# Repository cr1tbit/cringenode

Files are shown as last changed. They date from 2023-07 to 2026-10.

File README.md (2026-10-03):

# MOSNode

### A hackable IoT load switch prototyping platform

This device was probably the peak of my overengineeringness - I decided to create the most universal board for controlling low voltage outputs (Like LED stripes, motors, etc.).

In the end, it was too annoying to setup the matrix connections, so I just abandoned it.

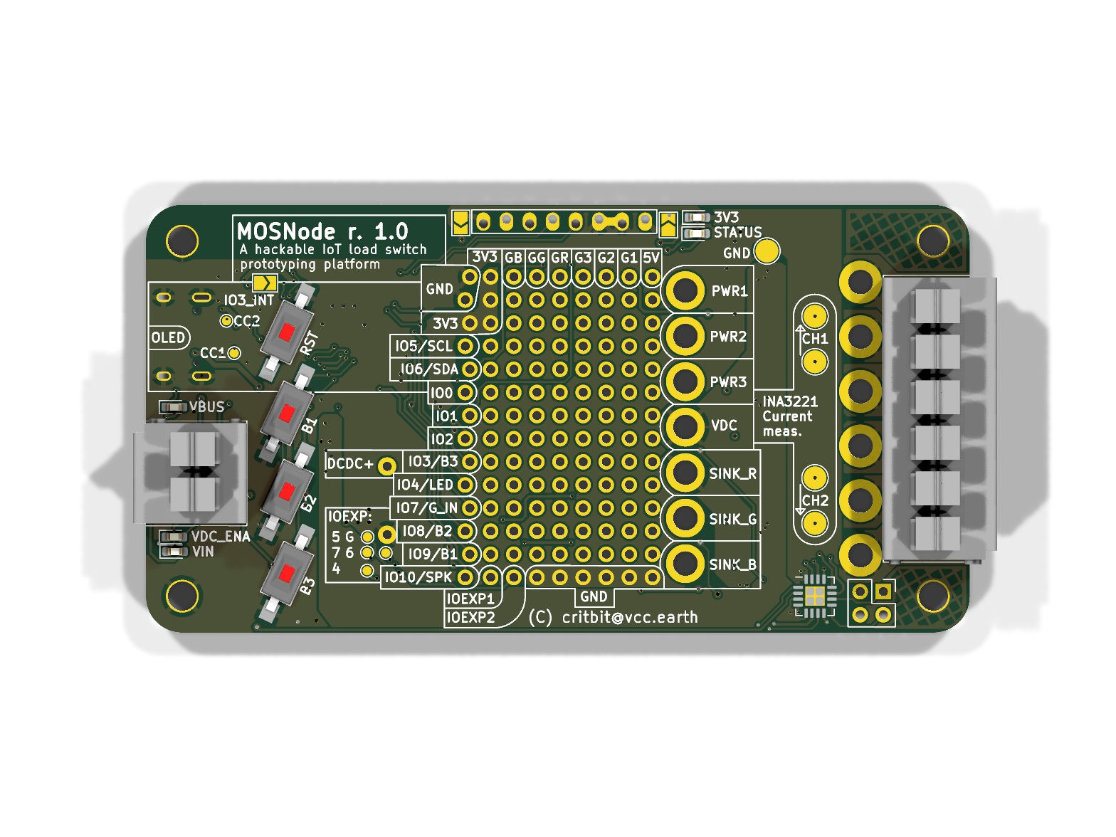
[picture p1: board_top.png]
render of board top


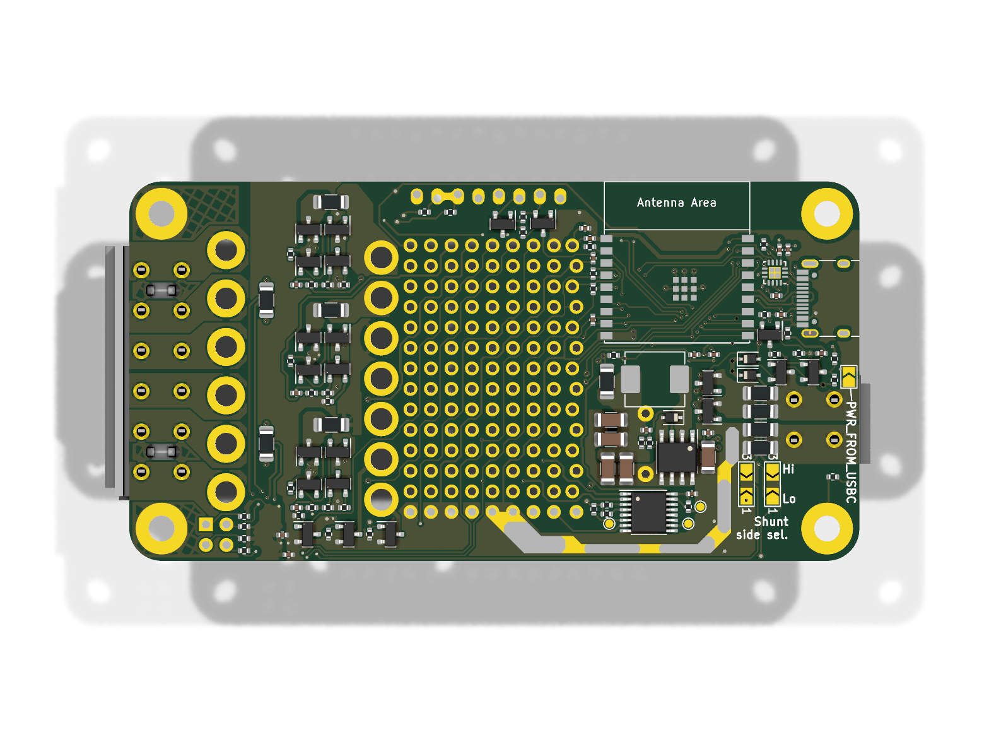
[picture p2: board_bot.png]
render of board bottom


## License

Copyright 2023 Jakub "cr1tbit" Sadowski.

* **Hardware** (KiCad sources, production files and this documentation) is
  licensed under the [CERN-OHL-P v2](LICENSE) (permissive). You may
  redistribute and modify it and make products using it under the terms of
  that licence.
* **Firmware** in [MOSNode-fw/](outduino-fw/) is licensed under the
  [MIT License](outduino-fw/LICENSE).

This source is distributed WITHOUT ANY EXPRESS OR IMPLIED WARRANTY, INCLUDING
OF MERCHANTABILITY, SATISFACTORY QUALITY AND FITNESS FOR A PARTICULAR PURPOSE.
Please see the CERN-OHL-P v2 for applicable conditions.

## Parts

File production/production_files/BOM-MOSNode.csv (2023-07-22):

Comment | Designator | Footprint | LCSC
WST03P06 | Q13,Q17,Q2,Q21,Q3 | SOT-23 | C105166
1k | R10,R29,R30,R32,R38,R43,R48,R53 | R_0402_1005Metric | C11702
FUSB302B01MPX | U5 | WQFN-14-1EP_2.5x2.5mm_P0.5mm_EP1.45x1.45mm | C132291
PCA9557PW | U4 | TSSOP-16_4.4x5mm_P0.65mm | C141380
47uH/2A | L1 | L_Abracon_ASPI-0630LR | C149588
200p | C1,C20,C22,C23,C24,C25,C9 | C_0402_1005Metric | C1530
10u | C11,C12 | C_0402_1005Metric | C15525
USB_C_Receptacle_USB2.0 | J4 | USB_C_Receptacle_HRO_TYPE-C-31-M-12 | C165948
0R/1206 | R12,R13,R3,R41,R46,R51 | R_1206_3216Metric_Pad1.30x1.75mm_HandSolder | C17888
1N5819WS | D1,D2,D3 | D_SOD-323 | C191023
AO3400A | Q4,Q7,Q8 | SOT-23 | C20917
S9015 | Q14,Q18,Q22,Q5 | SOT-23 | C2149
LED_0603 | D4,D5,D6,D7,D8 | LED_0603_1608Metric_Pad1.05x0.95mm_HandSolder | C2290
10k | R11,R14,R15,R20,R21,R22,R23,R24,R25,R26,R33,R34,R35,R36,R37,R40,R42,R45,R47,R5,R50,R52,R6,R7,R8,R9 | R_0402_1005Metric | C25744
15k | R39,R4,R44,R49 | R_0402_1005Metric | C25756
3k | R18,R19,R31 | R_0402_1005Metric | C25890
100n | C10,C13,C14,C15,C16,C17,C18,C19,C21,C8 | C_0402_1005Metric | C307331
50mR/1206 | R1,R2,R27,R28 | R_1206_3216Metric_Pad1.30x1.75mm_HandSolder | C601102
XL1509 | U1 | SOIC-8_3.9x4.9mm_P1.27mm | C74192
MMBT2222A | Q1,Q10,Q12,Q15,Q16,Q19,Q20,Q23,Q6,Q9 | SOT-23 | C8512
47uF/6.3V | C2,C4,C5,C6,C7 | C_1206_3216Metric | C96123
IN+ | J1 | DG235-5.0
FUSB_INT_IO3 | JP6 | SolderJumper-2_P1.3mm_Open_TrianglePad1.0x1.5mm
INA_PAD | TP5 | TestPoint_Pad_D2.5mm
B3 | SW4 | SW_SPST_FSMSM
TERM_BLOCK | J7 | DG235-5.0
CON_PAD | TP4 | MountingHole_2.7mm_M2.5_DIN965_Pad
INA_STA | J8 | PinHeader_2x02_P2.54mm_Vertical
CON_PAD | TP11 | MountingHole_2.7mm_M2.5_DIN965_Pad
INA_PAD | TP9 | TestPoint_Pad_D2.5mm
BOOT/B1 | SW2 | SW_SPST_FSMSM
TERM_BLOCK | J10 | DG235-5.0
TERM_BLOCK | J6 | DG235-5.0
INA_PAD | TP1 | TestPoint_Pad_D2.5mm
IOPAD | TP20 | TestPoint_Pad_D1.0mm
IOPAD | TP14 | TestPoint_Pad_D1.0mm
IOPAD | TP16 | TestPoint_Pad_D1.0mm
GND_PAD | TP2 | TestPoint_Pad_D2.5mm
PWR_FROM_USBC | JP5 | SolderJumper-2_P1.3mm_Open_TrianglePad1.0x1.5mm
TERM_BLOCK | J12 | DG235-5.0
Proto_matrix_14x9+7 | J3 | Proto_matrix_14x9+7
C_THT | C3 | CP_Radial_D10.0mm_P7.50mm
IOPAD | TP15 | TestPoint_Pad_D1.0mm
IN- | J2 | DG235-5.0
IOPAD | TP17 | TestPoint_Pad_D1.0mm
RST | SW1 | SW_SPST_FSMSM
INA3221 | U3 | Texas_RGV_S-PVQFN-N16_EP2.1x2.1mm
B2 | SW3 | SW_SPST_FSMSM
3V3_FROM_USBC | JP4 | SolderJumper-2_P1.3mm_Open_TrianglePad1.0x1.5mm
INA_PAD | TP6 | TestPoint_Pad_D2.5mm
TERM_BLOCK | J11 | DG235-5.0
CON_PAD | TP8 | MountingHole_2.7mm_M2.5_DIN965_Pad
CON_PAD | TP3 | MountingHole_2.7mm_M2.5_DIN965_Pad
Lichtenprog_conn | J5 | Lichtenprog
IOPAD | TP19 | TestPoint_Pad_D1.0mm
CON_PAD | TP10 | MountingHole_2.7mm_M2.5_DIN965_Pad
TERM_BLOCK | J9 | DG235-5.0
CON_PAD | TP7 | MountingHole_2.7mm_M2.5_DIN965_Pad
ESP32-C3-WROOM-02 | U2 | ESP32-C3-WROOM-02
IOPAD | TP12 | TestPoint_Pad_D1.0mm
SCR | H4 | MountingHole_3.2mm_M3_Pad_TopOnly
SolderJumper_3_Open | JP2 | SolderJumper-3_P2.0mm_Open_TrianglePad1.0x1.5mm_NumberLabels
SCR | H1 | MountingHole_3.2mm_M3_Pad_TopOnly
IOPAD | TP13 | TestPoint_Pad_D1.0mm
PWR_FROM_USBC | JP1 | SolderJumper-2_P1.3mm_Open_TrianglePad1.0x1.5mm
IOPAD | TP18 | TestPoint_Pad_D1.0mm
SCR | H3 | MountingHole_3.2mm_M3_Pad_TopOnly
SCR | H2 | MountingHole_3.2mm_M3_Pad_TopOnly
SolderJumper_3_Open | JP3 | SolderJumper-3_P2.0mm_Open_TrianglePad1.0x1.5mm_NumberLabels

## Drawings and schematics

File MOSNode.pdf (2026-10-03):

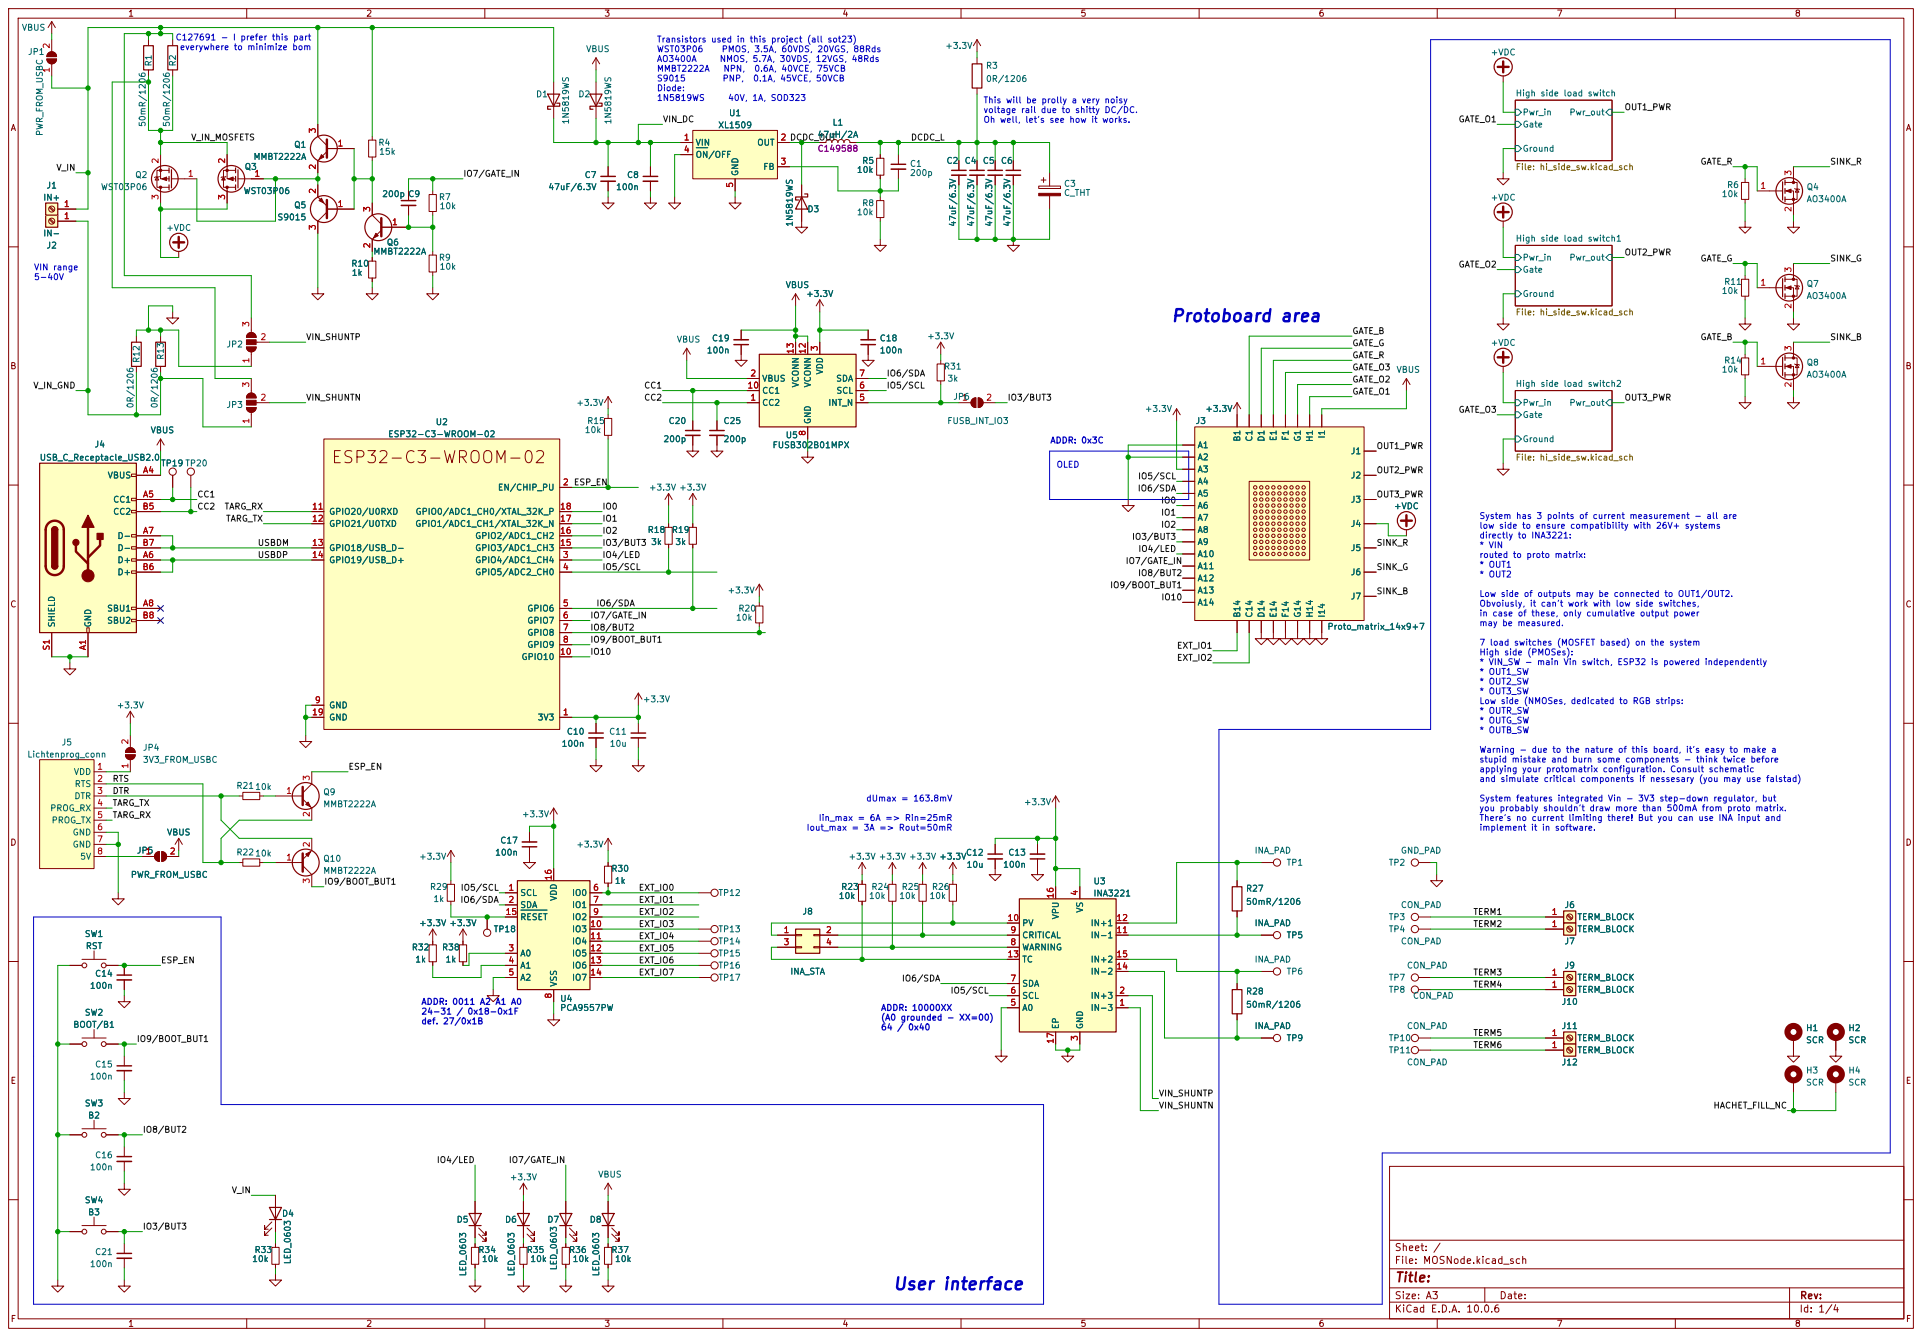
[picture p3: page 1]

voltage rail due to shitty DC/DC. Oh well, let's see how it works. User interface

everywhere to minimize bom

This will be prolly a very noisy

System has 3 points of current measurement - all are
low side to ensure compatibility with 26V+ systems
directly to INA3221: * VIN

routed to proto matrix: * OUT1

* OUT2 Low side of outputs may be connected to OUT1/OUT2.

Obvoiusly, it can't work with low side switches,
in case of these, only cumulative output power may be measured. 7 load switches (MOSFET based) on the system

High side (PMOSes): * VIN_SW - main Vin switch, ESP32 is powered independently

Warning - due to the nature of this board, it's easy to make a
stupid mistake and burn some components - think twice before applying your protomatrix configuration. Consult schematic and simulate critical components if nessesary (you may use falstad)

System features integrated Vin - 3V3 step-down regulator, but you probably shouldn't draw more than 500mA from proto matrix. There's no current limiting there! But you can use INA input and

implement it in software.

IN-2 14 IN+2 15 VPU 16 EP 17

Size: A3 | Rev: | F Date:
KiCad E.D.A. 10.0.6 | Id: 1/4

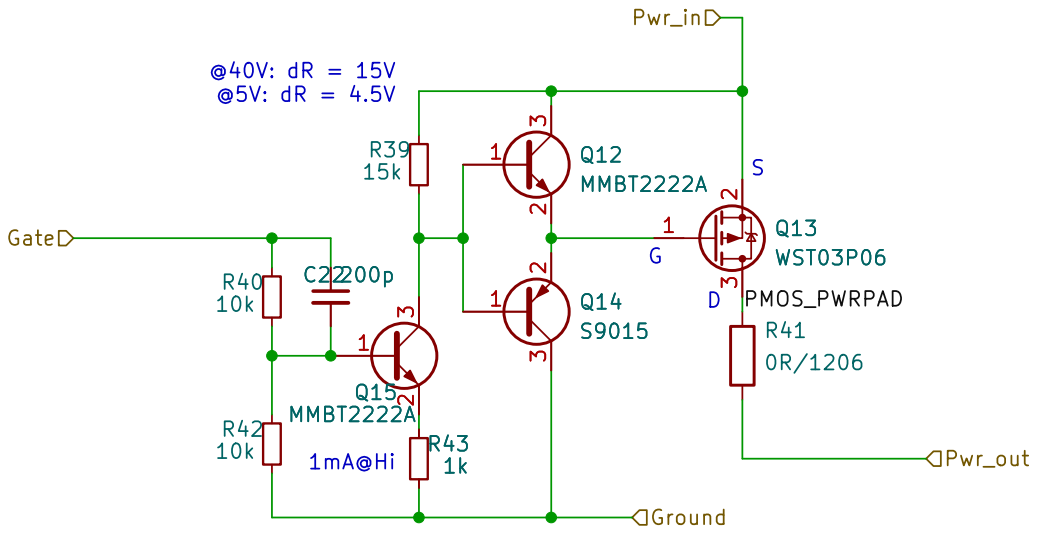
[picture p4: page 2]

Sheet: /High side load switch1/
File: hi_side_sw.kicad_sch
Title:

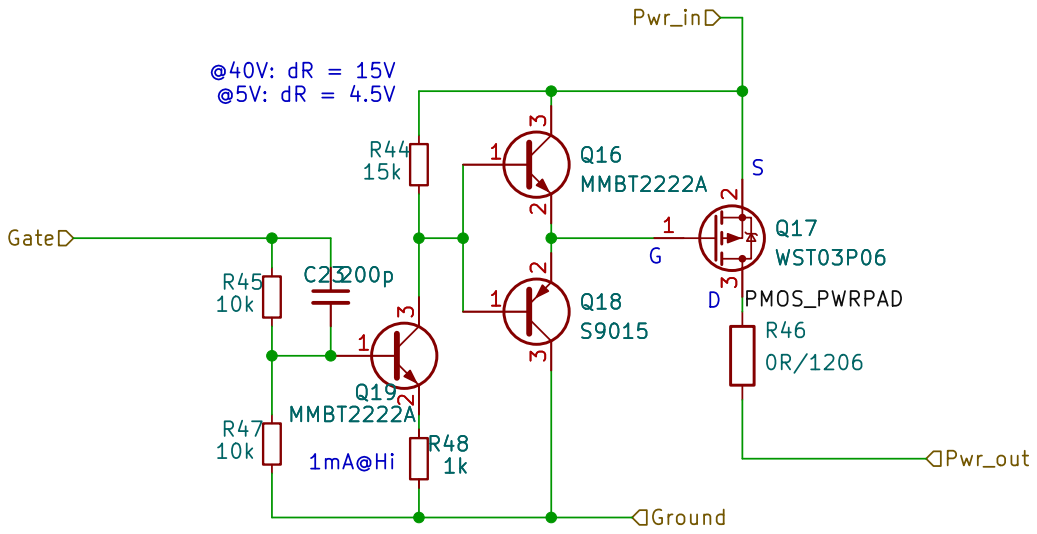
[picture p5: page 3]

Sheet: /High side load switch/
File: hi_side_sw.kicad_sch
Title:

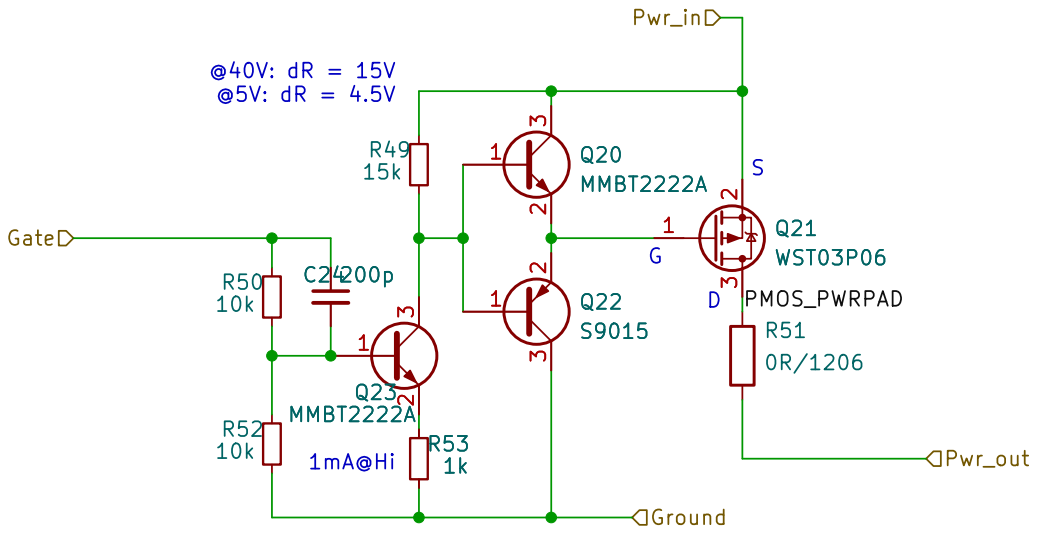
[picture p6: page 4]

Sheet: /High side load switch2/
File: hi_side_sw.kicad_sch
Title:

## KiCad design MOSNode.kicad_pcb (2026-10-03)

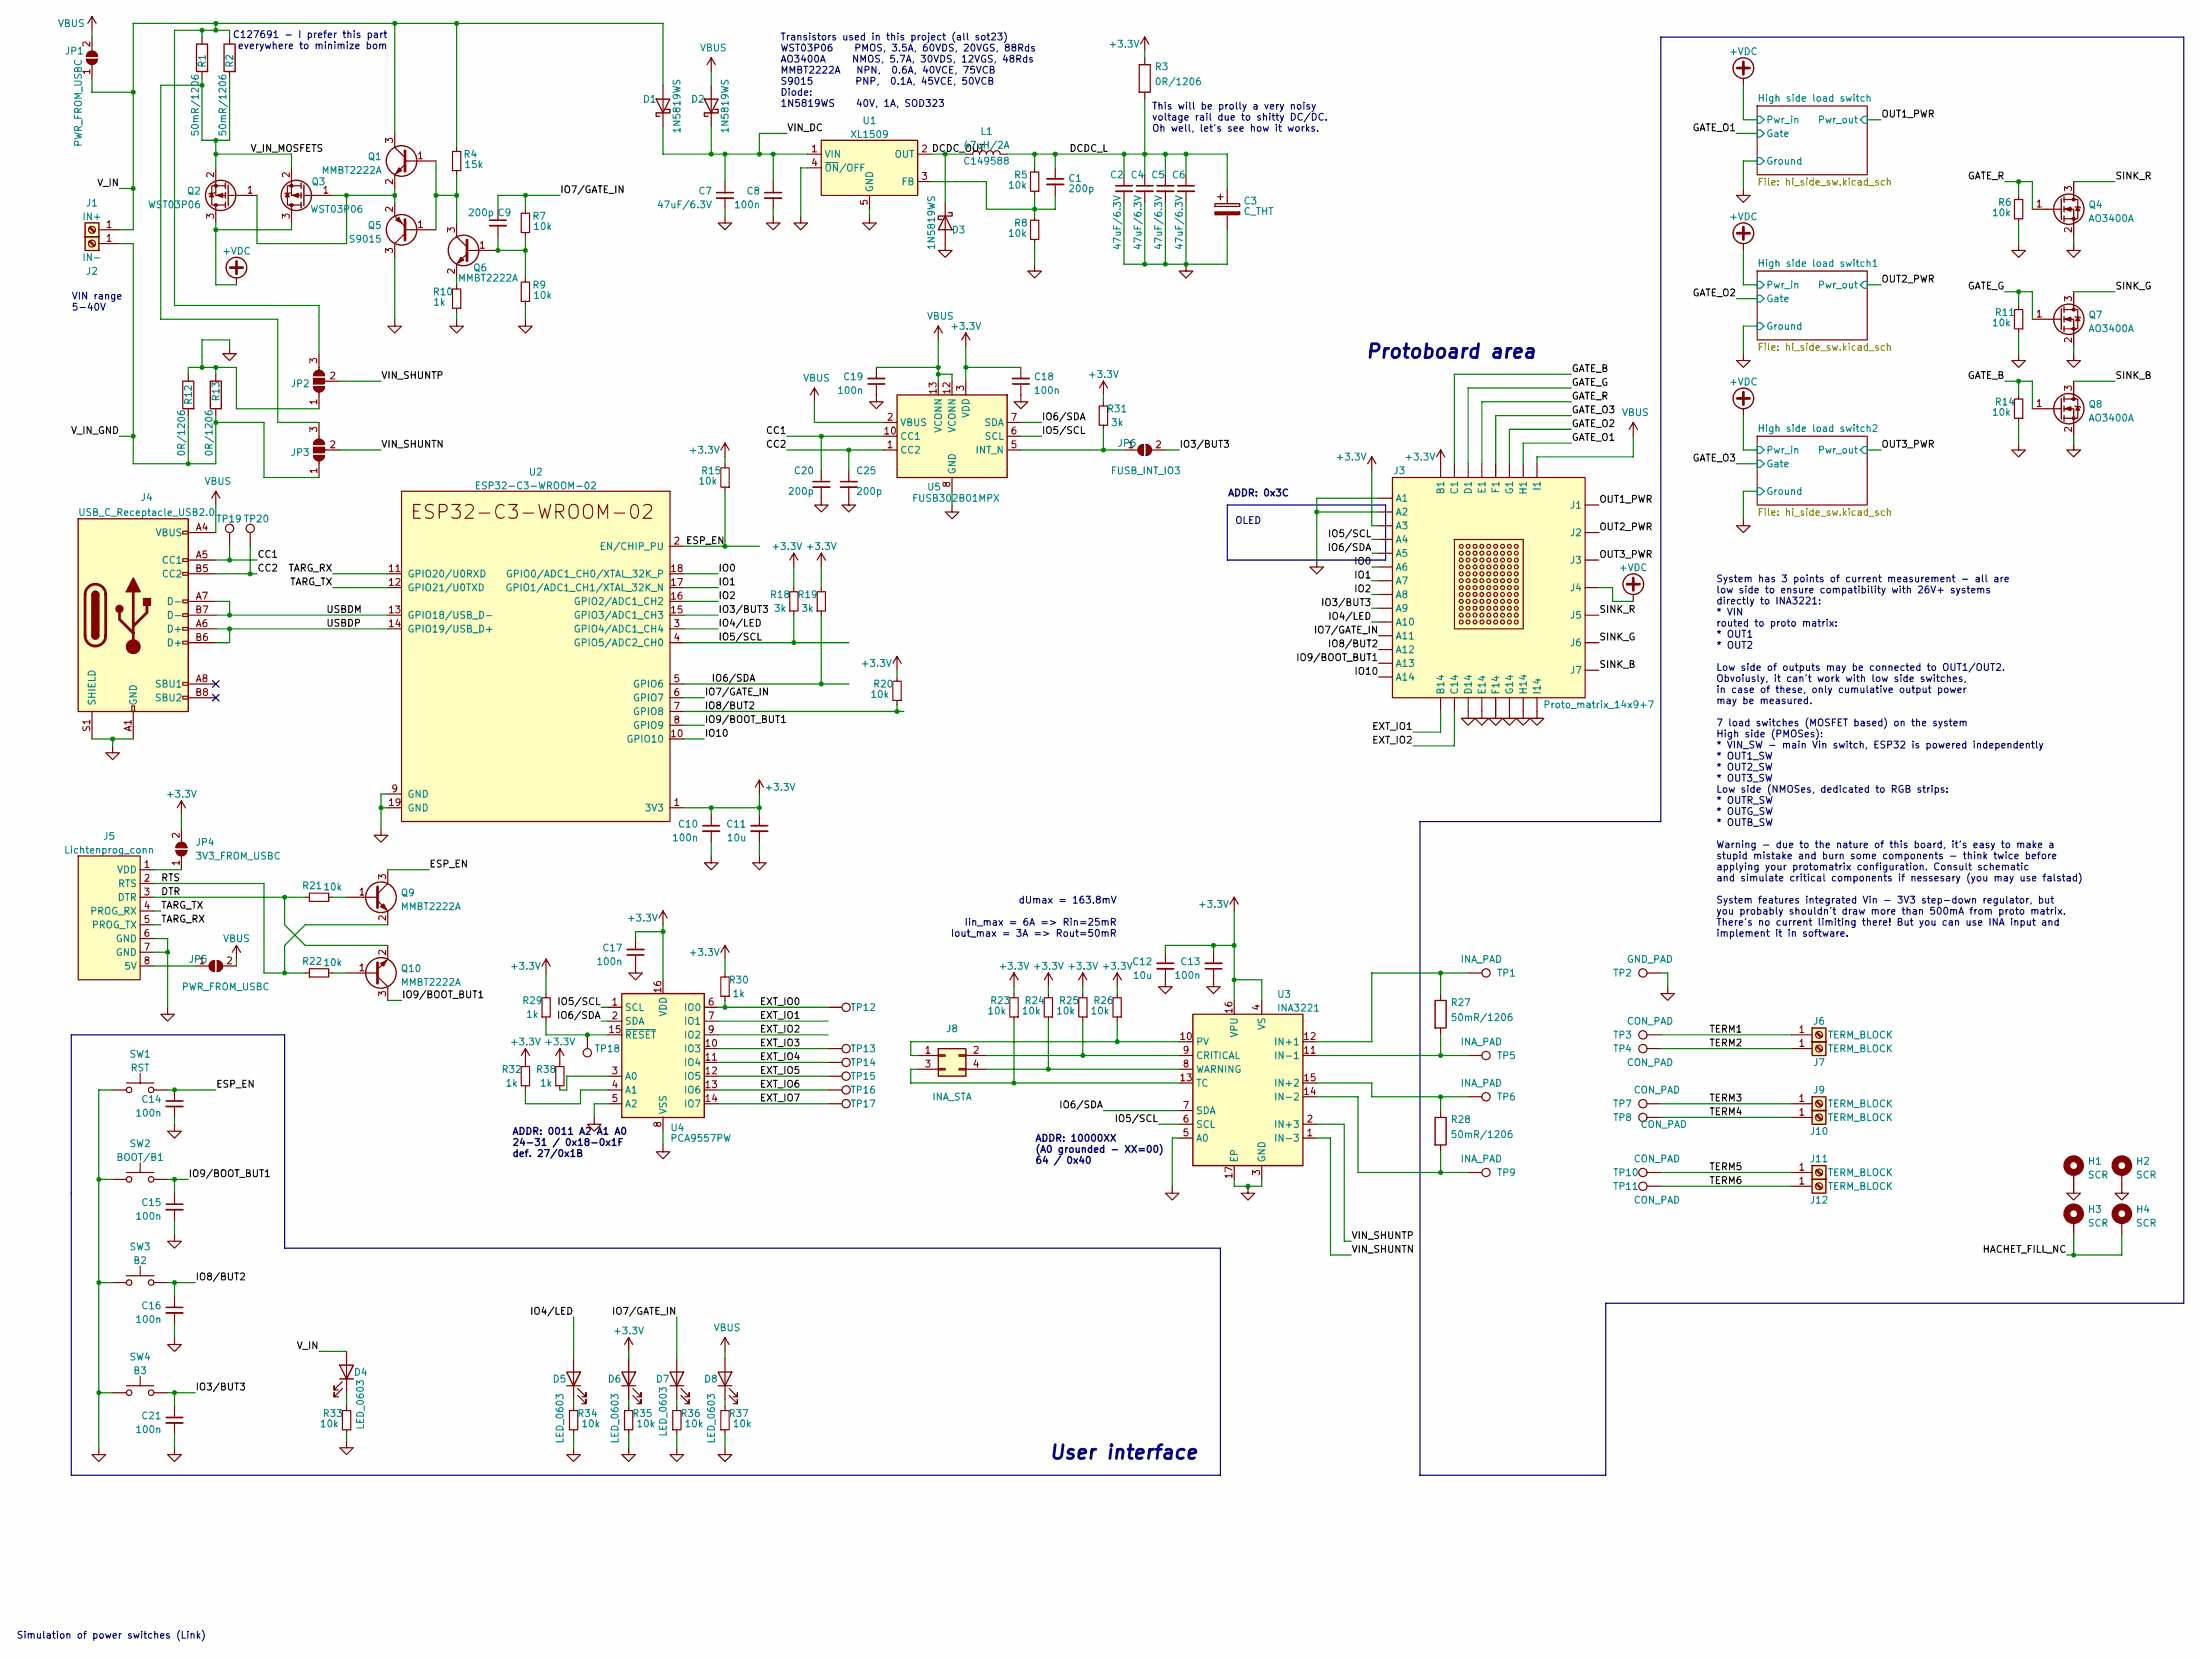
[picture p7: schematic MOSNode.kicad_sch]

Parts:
C1, C9, C20, C25: 200p; C_0402_1005Metric; LCSC C1530
C2, C4, C5, C6, C7: 47uF/6.3V; C_1206_3216Metric; LCSC C96123
C3: C_THT; CP_Radial_D10.0mm_P7.50mm; LCSC DNP
C8, C10, C13, C14, C15, C16, C17, C18, C19, C21: 100n; C_0402_1005Metric; LCSC C307331
C11, C12: 10u; C_0402_1005Metric; LCSC C15525
D1, D2, D3: 1N5819WS; D_SOD-323; LCSC C191023
D4, D5, D6, D7, D8: LED_0603; LED_0603_1608Metric_Pad1.05x0.95mm_HandSolder; LCSC C2290
H1, H2, H3, H4: SCR; MountingHole_3.2mm_M3_Pad_TopOnly; LCSC DNP
J1: IN+; DG235-5.0; LCSC DNP
J2: IN-; DG235-5.0; LCSC DNP
J3: Proto_matrix_14x9+7; LCSC DNP
J4: USB_C_Receptacle_USB2.0; USB_C_Receptacle_HRO_TYPE-C-31-M-12; LCSC C165948
J5: Lichtenprog_conn; Lichtenprog; LCSC DNP
J6, J7, J9, J10, J11, J12: TERM_BLOCK; DG235-5.0; LCSC DNP
J8: INA_STA; PinHeader_2x02_P2.54mm_Vertical; LCSC DNP
JP1, JP5: PWR_FROM_USBC; SolderJumper-2_P1.3mm_Open_TrianglePad1.0x1.5mm; LCSC DNP
JP2, JP3: SolderJumper_3_Open; SolderJumper-3_P2.0mm_Open_TrianglePad1.0x1.5mm_NumberLabels; LCSC DNP
JP4: 3V3_FROM_USBC; SolderJumper-2_P1.3mm_Open_TrianglePad1.0x1.5mm; LCSC DNP
JP6: FUSB_INT_IO3; SolderJumper-2_P1.3mm_Open_TrianglePad1.0x1.5mm; LCSC DNP
L1: 47uH/2A; L_Abracon_ASPI-0630LR; JLC C149588
Q1, Q6, Q9, Q10: MMBT2222A; SOT-23; LCSC C8512
Q2, Q3: WST03P06; SOT-23; LCSC C105166
Q4, Q7, Q8: AO3400A; SOT-23; LCSC C20917
Q5: S9015; SOT-23; LCSC C2149
R1, R2, R27, R28: 50mR/1206; R_1206_3216Metric_Pad1.30x1.75mm_HandSolder; LCSC C601102
R3, R12, R13: 0R/1206; R_1206_3216Metric_Pad1.30x1.75mm_HandSolder; LCSC C17888
R4: 15k; R_0402_1005Metric; LCSC C25756
R5, R6, R7, R8, R9, R11, R14, R15, R20, R21, R22, R23, R24, R25, R26, R33, R34, R35, R36, R37: 10k; R_0402_1005Metric; LCSC C25744
R10, R29, R30, R32, R38: 1k; R_0402_1005Metric; LCSC C11702
R18, R19, R31: 3k; R_0402_1005Metric; LCSC C25890
SW1: RST; SW_SPST_FSMSM; LCSC DNP
SW2: BOOT/B1; SW_SPST_FSMSM; LCSC DNP
SW3: B2; SW_SPST_FSMSM; LCSC DNP
SW4: B3; SW_SPST_FSMSM; LCSC DNP
TP1, TP5, TP6, TP9: INA_PAD; TestPoint_Pad_D2.5mm; LCSC DNP
TP2: GND_PAD; TestPoint_Pad_D2.5mm; LCSC DNP
TP3, TP4, TP7, TP8, TP10, TP11: CON_PAD; MountingHole_2.7mm_M2.5_DIN965_Pad; LCSC DNP
TP12, TP13, TP14, TP15, TP16, TP17, TP18, TP19, TP20: IOPAD; TestPoint_Pad_D1.0mm; LCSC DNP
U1: XL1509; SOIC-8_3.9x4.9mm_P1.27mm; LCSC C74192
U2: ESP32-C3-WROOM-02; LCSC DNP
U3: INA3221; Texas_RGV_S-PVQFN-N16_EP2.1x2.1mm; LCSC DNP
U4: PCA9557PW; TSSOP-16_4.4x5mm_P0.65mm; LCSC C141380
U5: FUSB302B01MPX; WQFN-14-1EP_2.5x2.5mm_P0.5mm_EP1.45x1.45mm; LCSC C132291

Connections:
+3.3V: C10.1, C11.1, C12.1, C13.2, C17.2, C18.2, D6.2 (A), J3.A3, J3.B1, JP4.2 (B), R3.1, R15.2, R18.2, R19.2, R20.2, R23.2, R24.2, R25.2, R26.2, R29.2, R30.2, R31.2, R32.2, R38.2, U2.1 (3V3), U3.4 (VS), U3.16 (VPU), U4.16 (VDD), U5.3 (VDD), U5.4 (VDD)
+VDC: J3.J4, Q2.3 (S), Q3.3 (S); also elsewhere on the board
/CC1: C20.1, J4.A5 (CC1), TP19.1, U5.10 (CC1), U5.11 (CC1)
/CC2: C25.1, J4.B5 (CC2), TP20.1, U5.1 (CC2), U5.14 (CC2)
/DCDC_L: C1.1, C2.1, C3.1, C4.1, C5.1, C6.1, L1.2, R3.2, R5.2
/DCDC_OUT: D3.1 (K), L1.1, U1.2 (OUT)
/DTR: J5.3 (DTR), Q10.2 (E), R21.1
/ESP_EN: C14.1, Q9.3 (C), R15.1, SW1.2, U2.2 (EN/CHIP_PU)
/EXT_IO0: R30.1, TP12.1, U4.6 (IO0)
/EXT_IO1: J3.B14, U4.7 (IO1)
/EXT_IO2: J3.C14, U4.9 (IO2)
/EXT_IO3: TP13.1, U4.10 (IO3)
/EXT_IO4: TP14.1, U4.11 (IO4)
/EXT_IO5: TP15.1, U4.12 (IO5)
/EXT_IO6: TP16.1, U4.13 (IO6)
/EXT_IO7: TP17.1, U4.14 (IO7)
/GATE_B: J3.C1, Q8.1 (G), R14.2
/GATE_G: J3.D1, Q7.1 (G), R11.2
/GATE_O1: J3.H1; also elsewhere on the board
/GATE_O2: J3.G1; also elsewhere on the board
/GATE_O3: J3.F1; also elsewhere on the board
/GATE_R: J3.E1, Q4.1 (G), R6.2
/HACHET_FILL_NC: H3.1, H4.1
/IO0: J3.A6, U2.18 (GPIO0/ADC1_CH0/XTAL_32K_P)
/IO1: J3.A7, U2.17 (GPIO1/ADC1_CH1/XTAL_32K_N)
/IO2: J3.A8, U2.16 (GPIO2/ADC1_CH2)
/IO3/BUT3: C21.1, J3.A9, JP6.2 (B), SW4.2, U2.15 (GPIO3/ADC1_CH3)
/IO4/LED: D5.2 (A), J3.A10, U2.3 (GPIO4/ADC1_CH4)
/IO5/SCL: J3.A4, R18.1, U2.4 (GPIO5/ADC2_CH0), U3.6 (SCL), U4.1 (SCL), U5.6 (SCL)
/IO6/SDA: J3.A5, R19.1, U2.5 (GPIO6), U3.7 (SDA), U4.2 (SDA), U5.7 (SDA)
/IO7/GATE_IN: C9.1, D7.2 (A), J3.A11, R7.2, U2.6 (GPIO7)
/IO8/BUT2: C16.1, J3.A12, R20.1, SW3.2, U2.7 (GPIO8)
/IO9/BOOT_BUT1: C15.1, J3.A13, Q10.3 (C), SW2.2, U2.8 (GPIO9)
/IO10: J3.A14, U2.10 (GPIO10)
/OUT1_PWR: J3.J1; also elsewhere on the board
/OUT2_PWR: J3.J2; also elsewhere on the board
/OUT3_PWR: J3.J3; also elsewhere on the board
/RTS: J5.2 (RTS), Q9.2 (E), R22.1
/SINK_B: J3.J7, Q8.3 (D)
/SINK_G: J3.J6, Q7.3 (D)
/SINK_R: J3.J5, Q4.3 (D)
/TARG_RX: J5.5 (PROG_TX), U2.11 (GPIO20/U0RXD)
/TARG_TX: J5.4 (PROG_RX), U2.12 (GPIO21/U0TXD)
/TERM1: J6.1, TP3.1
/TERM2: J7.1, TP4.1
/TERM3: J9.1, TP7.1
/TERM4: J10.1, TP8.1
/TERM5: J11.1, TP10.1
/TERM6: J12.1, TP11.1
/USBDM: J4.A7 (D-), J4.B7 (D-), U2.13 (GPIO18/USB_D-)
/USBDP: J4.A6 (D+), J4.B6 (D+), U2.14 (GPIO19/USB_D+)
/VIN_DC: C7.1, C8.1, D1.1 (K), D2.1 (K), U1.1 (VIN)
/VIN_SHUNTN: JP3.2 (C), U3.1 (IN-3)
/VIN_SHUNTP: JP2.2 (C), U3.2 (IN+3)
/V_IN: D1.2 (A), D4.2 (A), J1.1, JP1.1 (A), JP2.3 (B), Q1.3 (C), R1.1, R2.1, R4.2
/V_IN_GND: J2.1, JP3.1 (A), R12.2, R13.2
/V_IN_MOSFETS: JP3.3 (B), Q2.2 (D), Q3.2 (D), R1.2, R2.2
GND: C2.2, C3.2, C4.2, C5.2, C6.2, C7.2, C8.2, C10.2, C11.2, C12.2, C13.1, C14.2, C15.2, C16.2, C17.1, C18.1, C19.1, C20.2, C21.2, C25.2, D3.2 (A), H1.1, H2.1, J3.A1, J3.A2, J3.D14, J3.E14, J3.F14, J3.G14, J3.H14, J3.I14, J4.A1 (GND), J4.A12 (GND), J4.B1 (GND), J4.B12 (GND), J4.S1 (SHIELD), J5.6 (GND), J5.7 (GND), JP2.1 (A), Q4.2 (S), Q5.3 (C), Q7.2 (S), Q8.2 (S), R6.1, R8.1, R9.1, R10.1, R11.1, R12.1, R13.1, R14.1, R33.1, R34.1, R35.1, R36.1, R37.1, SW1.1, SW2.1, SW3.1, SW4.1, TP2.1, U1.4 (~ON/OFF), U1.5 (GND), U1.6 (GND), U1.7 (GND), U1.8 (GND), U2.9 (GND), U2.19 (GND), U3.3 (GND), U3.5 (A0), U3.17 (EP), U4.5 (A2), U4.8 (VSS), U5.8 (GND), U5.9 (GND), U5.15 (GND); also elsewhere on the board
unnamed: D4.1 (K), R33.2
unnamed: D5.1 (K), R34.2
unnamed: D6.1 (K), R35.2
unnamed: D7.1 (K), R36.2
unnamed: D8.1 (K), R37.2
unnamed: J5.8 (5V), JP5.1 (A)
unnamed: J5.1 (VDD), JP4.1 (A)
unnamed: J8.1, R26.1, U3.10 (PV)
unnamed: J8.2, R25.1, U3.9 (CRITICAL)
unnamed: J8.3, R23.1, U3.13 (TC)
unnamed: J8.4, R24.1, U3.8 (WARNING)
unnamed: JP6.1 (A), R31.1, U5.5 (INT_N)
unnamed: Q1.1 (B), Q5.1 (B), Q6.3 (C), R4.1
unnamed: Q1.2 (E), Q2.1 (G), Q3.1 (G), Q5.2 (E)
unnamed: C9.2, Q6.1 (B), R7.1, R9.2
unnamed: Q6.2 (E), R10.2
unnamed: Q9.1 (B), R21.2
unnamed: Q10.1 (B), R22.2
unnamed: C1.2, R5.1, R8.2, U1.3 (FB)
unnamed: R27.1, TP1.1, U3.12 (IN+1)
unnamed: R28.1, TP6.1, U3.15 (IN+2)
unnamed: R27.2, TP5.1, U3.11 (IN-1)
unnamed: R28.2, TP9.1, U3.14 (IN-2)
unnamed: R38.1, U4.3 (A0)
unnamed: R32.1, U4.4 (A1)
unnamed: R29.1, TP18.1, U4.15 (~RESET)
VBUS: C19.2, D2.2 (A), D8.2 (A), J3.I1, J4.A4 (VBUS), J4.A9 (VBUS), J4.B4 (VBUS), J4.B9 (VBUS), JP1.2 (B), JP5.2 (B), U5.2 (VBUS), U5.12 (VCONN), U5.13 (VCONN)

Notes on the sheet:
ADDR: 0011 A2 A1 A0 24-31 / 0x18-0x1F def. 27/0x1B
Transistors used in this project (all sot23) WST03P06 PMOS, 3.5A, 60VDS, 20VGS, 88Rds AO3400A NMOS, 5.7A, 30VDS, 12VGS, 48Rds MMBT2222A NPN, 0.6A, 40VCE, 75VCB S9015 PNP, 0.1A, 45VCE, 50VCB Diode: 1N5819WS 40V, 1A, SOD323
Protoboard area
ADDR: 10000XX (A0 grounded - XX=00) 64 / 0x40
System has 3 points of current measurement - all are low side to ensure compatibility with 26V+ systems directly to INA3221: * VIN routed to proto matrix: * OUT1 * OUT2 Low side of outputs may be connected to OUT1/OUT2. Obvoiusly, it can't work with low side switches, in case of these, only cumulat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
VIN range 5-40V
This will be prolly a very noisy voltage rail due to shitty DC/DC. Oh well, let's see how it works.
OLED
ADDR: 0x3C
User interface
C127691 - I prefer this part everywhere to minimize bom
Simulation of power switches (Link)
dUmax = 163.8mV Iin_max = 6A => Rin=25mR Iout_max = 3A => Rout=50mR

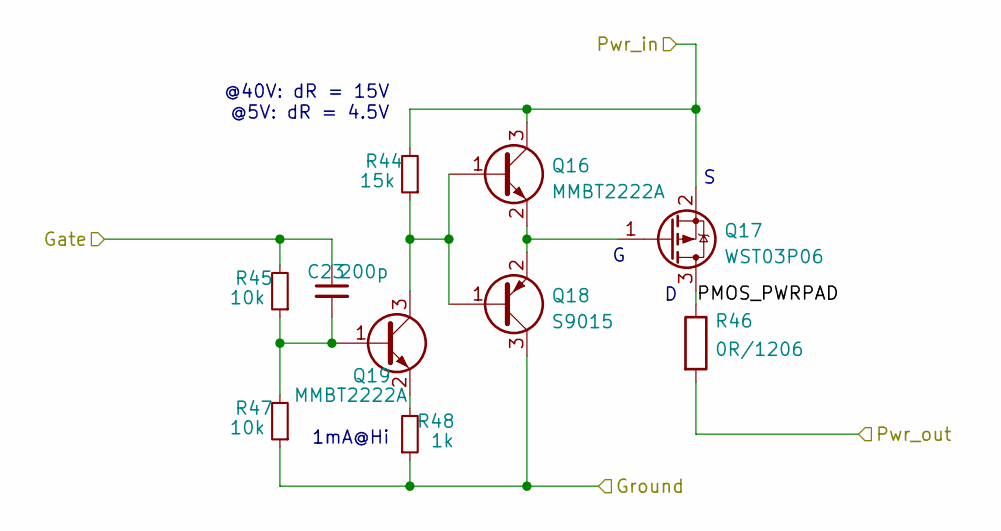
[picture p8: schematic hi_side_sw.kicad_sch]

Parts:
C23: 200p; C_0402_1005Metric; LCSC C1530
Q16, Q19: MMBT2222A; SOT-23; LCSC C8512
Q17: WST03P06; SOT-23; LCSC C105166
Q18: S9015; SOT-23; LCSC C2149
R44: 15k; R_0402_1005Metric; LCSC C25756
R45, R47: 10k; R_0402_1005Metric; LCSC C25744
R46: 0R/1206; R_1206_3216Metric_Pad1.30x1.75mm_HandSolder; LCSC C17888
R48: 1k; R_0402_1005Metric; LCSC C11702

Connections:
+VDC: Q16.3 (C), Q17.2 (D), R44.2; also elsewhere on the board
/GATE_O1: C23.1, R45.2; also elsewhere on the board
/High side load switch/PMOS_PWRPAD: Q17.3 (S), R46.1
/OUT1_PWR: R46.2; also elsewhere on the board
GND: Q18.3 (C), R47.1, R48.1; also elsewhere on the board
unnamed: Q16.1 (B), Q18.1 (B), Q19.3 (C), R44.1
unnamed: Q16.2 (E), Q17.1 (G), Q18.2 (E)
unnamed: C23.2, Q19.1 (B), R45.1, R47.2
unnamed: Q19.2 (E), R48.2

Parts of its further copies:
C22, C24: 200p; C_0402_1005Metric; LCSC C1530
Q12, Q15, Q20, Q23: MMBT2222A; SOT-23; LCSC C8512
Q13, Q21: WST03P06; SOT-23; LCSC C105166
Q14, Q22: S9015; SOT-23; LCSC C2149
R39, R49: 15k; R_0402_1005Metric; LCSC C25756
R40, R42, R50, R52: 10k; R_0402_1005Metric; LCSC C25744
R41, R51: 0R/1206; R_1206_3216Metric_Pad1.30x1.75mm_HandSolder; LCSC C17888
R43, R53: 1k; R_0402_1005Metric; LCSC C11702

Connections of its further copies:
+VDC: Q12.3 (C), Q13.2 (D), Q20.3 (C), Q21.2 (D), R39.2, R49.2; also elsewhere on the board
/GATE_O2: C22.1, R40.2; also elsewhere on the board
/GATE_O3: C24.1, R50.2; also elsewhere on the board
/High side load switch1/PMOS_PWRPAD: Q13.3 (S), R41.1
/High side load switch2/PMOS_PWRPAD: Q21.3 (S), R51.1
/OUT2_PWR: R41.2; also elsewhere on the board
/OUT3_PWR: R51.2; also elsewhere on the board
GND: Q14.3 (C), Q22.3 (C), R42.1, R43.1, R52.1, R53.1; also elsewhere on the board
unnamed: Q12.1 (B), Q14.1 (B), Q15.3 (C), R39.1
unnamed: Q12.2 (E), Q13.1 (G), Q14.2 (E)
unnamed: C22.2, Q15.1 (B), R40.1, R42.2
unnamed: Q15.2 (E), R43.2
unnamed: Q20.1 (B), Q22.1 (B), Q23.3 (C), R49.1
unnamed: Q20.2 (E), Q21.1 (G), Q22.2 (E)
unnamed: C24.2, Q23.1 (B), R50.1, R52.2
unnamed: Q23.2 (E), R53.2

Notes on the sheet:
1mA@Hi
@40V: dR = 15V @5V: dR = 4.5V

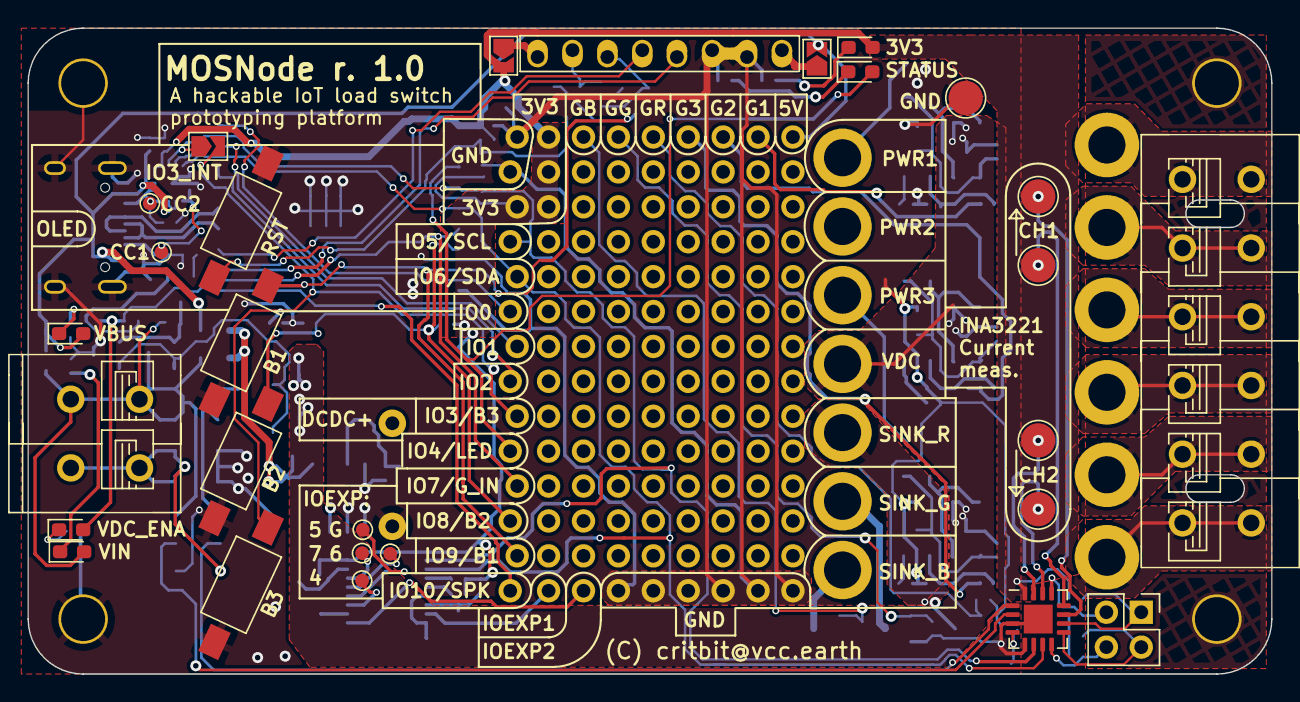
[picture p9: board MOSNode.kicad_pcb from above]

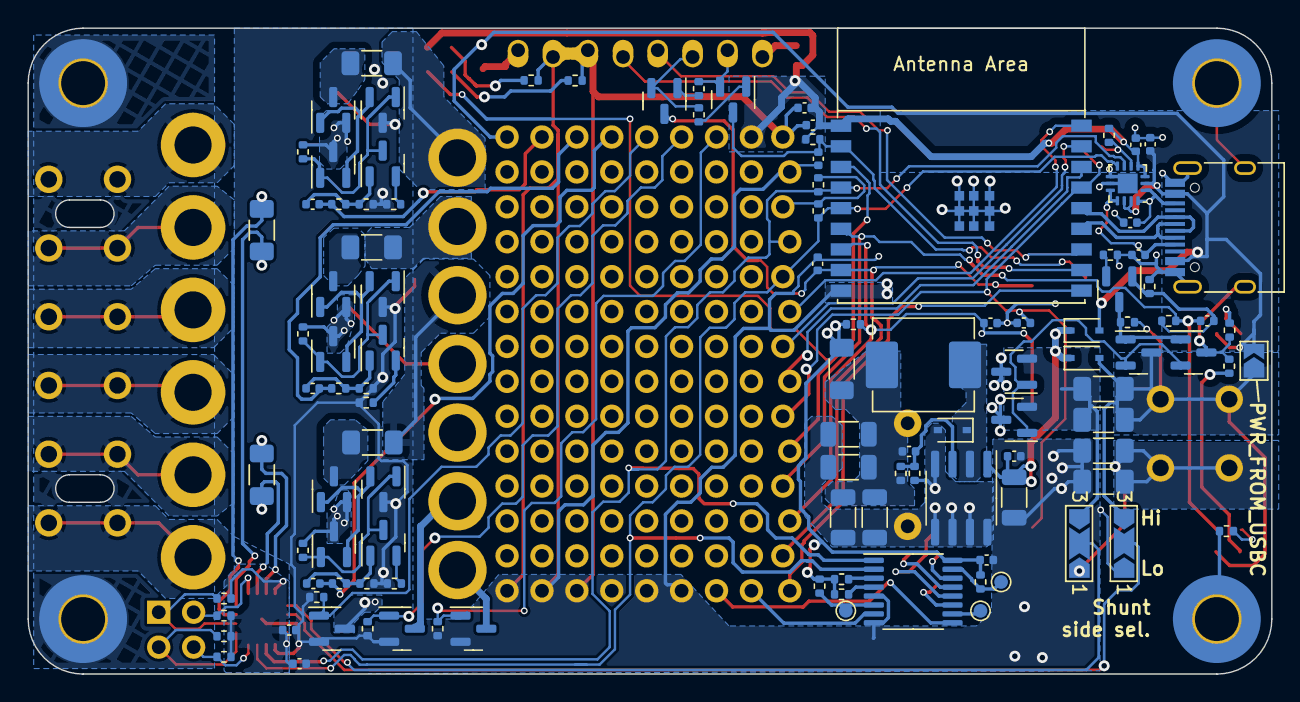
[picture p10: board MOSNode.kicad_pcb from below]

Board: 2 copper layers, 90.5 x 47.0 mm, 158 parts (116 on the bottom side), 100 nets.

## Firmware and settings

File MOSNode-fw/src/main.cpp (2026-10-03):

#include <cmath>

#include <Arduino.h>
#include <Wire.h>

#include <Button2.h>
#include <INA3221.h>

#include <alfalog.h>
#include "advancedOledLogger.h"

#include <commonFwUtils.h>
#include <powerPathHandler.h>
#include "pinDefs.h"

#define FW_REV "0.1.0"

TwoWire i2c = TwoWire(0);

void uartHandle(const char* str){
  Serial.println(str);
}

AdvancedOledLogger aOledLogger = 
  AdvancedOledLogger(i2c, LOG_INFO, OLED_128x32, OLED_UPSIDE_DOWN);
SerialLogger serialLogger = SerialLogger(uartHandle, LOG_DEBUG, ALOG_FANCY);
Button2 userButton = Button2();

powerPathHandler pph = powerPathHandler();

void setup() {
  Serial.begin(115200);
  // Serial.setTxTimeoutMs(0); // prevent logger slowdown when no usb connected
  Serial.println("begin...");
  // delay(3000);
  // bootloopOnButtonPress(PIN_B2);
  i2c.begin(IO6_SDA, IO5_SCL);
      
  AlfaLogger.addBackend(&aOledLogger);
  AlfaLogger.addBackend(&serialLogger);
  AlfaLogger.begin();
  ALOGI("display started");

  ALOG_I2CLS(i2c);

  userButton.begin(IO9_BUT1, INPUT_PULLUP, false);
  userButton.setTapHandler([](Button2 & b){
      ALOGI("button tapped");
    }
  );

  aOledLogger.setTopBarText(BAR_WIFI_IP, "MOSNode r. " FW_REV);

  pph.pinMap[GATE_1] = IO2;
  pph.pinMap[GATE_2] = IO1;
  pph.pinMap[GATE_3] = IO0;

  pph.init(&i2c);
  pph.setMainSwitch(PWR_ON);
}

void loop() {
  handle_io_pattern(IO4_LED, PATTERN_HBEAT);
  userButton.loop();
  vTaskDelay(50/portTICK_PERIOD_MS);

  static int counter = 0;
  pph.setPWM(GATE_1, sin(counter/16.0)*128 + 128);

  if (counter++ % 8 == 0){
    aOledLogger.redraw();
    pph.logCurrent();
  }
}

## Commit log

2022-10-12 initing stuff
    [cringenode.kicad_pcb, cringenode.kicad_sch]
2022-10-23 work rly hard on schematic
    [cringenode.kicad_sch]
2022-10-24 mostly finishing schematic
    [cringenode.kicad_sch]
2022-10-29 pivoting to protoboard-matrix
    [cringenode.kicad_pcb, cringenode.kicad_sch]
2022-11-12 finish this unholy abomination
    [cringenode.kicad_pcb, cringenode.kicad_sch, hi_side_sw.kicad_sch]
2023-07-09 replace audio with IOexp + PD controller, project rename
    [MOSNode.kicad_pcb, MOSNode.kicad_sch, cringenode.kicad_pcb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]
2023-09-17 wrap current handling in class
2026-10-03 add license, description, schematic pdf
    [MOSNode.kicad_pcb, MOSNode.kicad_sch, hi_side_sw.kicad_sch]
